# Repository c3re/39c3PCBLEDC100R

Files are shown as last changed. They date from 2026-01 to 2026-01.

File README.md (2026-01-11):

# 39c3PCBLEDC100R

The 39c3PCBLEDC100 is a Coaster for your drinks with option for LED and microcontroller upgrade. By stacking the coasters, you can also build nice blinky towers.

## Rev.0

### Electrical connections

Important: Do not power the board by USB and an external power supply at the same time!
The Din pin of the first LED is connected to pin D4 (GPIO2) of the Wemos D1 mini. ...well, not directly: there is a MOS-FET Transistor in between to shift the signal level from 3.3V to 5V. 
Two of the mounting holes are connected to GND, two of the holes are connected to 5V. You can use this feature to stack multiple 39c3PCBLEDc100R Boards with brass spacers.

The button is connected to D3 (GPIO0) and GND. In WLED (Time & Macros -> Button actions) you can configure actions for short, long and double click.

## License
    
39c3PCBLEDC100R © 2025 by c3RE is licensed under CC BY 4.0. To view a copy of this license,   
visit http://creativecommons.org/licenses/by/4.0/

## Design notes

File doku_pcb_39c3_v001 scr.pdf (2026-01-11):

# 39c3PCBLEDC100R

## D er 39c3P C B LE D C 10 0 R ist v ielleicht ein G eträn keu ntersetzer

m it d er O p tio n au f ein LE D ⁻ u n d M icro co ntro ller⁻U p d ate.

## D u kan nst d ie U ntersetzer stap eln u n d d ein en eigen en

b lin ken d en Tu rm u n d an d ere O b jekte b au en .

## M ayb e th e 39c3P C B LE D C 10 0 R is a coaster fo r yo u r d rin ks w ith o p tio n fo r LE D an d m icro co ntro ller u p grad e. By stackin g th e

coasters, yo u can also b u ild n ice b lin ky tow ers.

# Elektrische Verbindungen/Electrical connections

Wichtig: Schließe das Board nie gleichzeitig an USB und eine externe Spannungsversorgung an!

## Der Din Pin der ersten LED ist mit dem Pin D4 (GPIO4) des Wemos D1 mini verbunden. Zwei

Befestigungslöcher sind mit GND verbunden, die anderen beiden mit 5V. Du kannst damit mehrere PCBs mit Messingabstandhaltern verbinden.

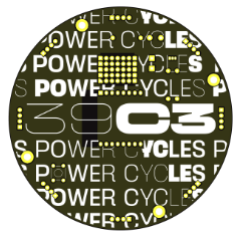
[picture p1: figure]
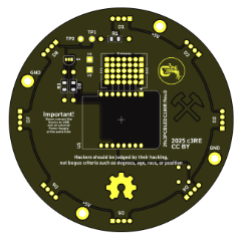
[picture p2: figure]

Important: Do not power the board by USB and an external power supply at the same time! The Din pin of the first LED is connected to pin D4 (GPIO2) of the Wemos D1 mini. Two of the mounting holes are connected to GND, two of the holes are connected to 5V. You can use this feature to stack multiple 39c3PCBLEDc100R Boards with brass spacers.

# Bevor es losgeht/before you start

Beginne mit den kleinsten Bauteilen in der Reihenfolge: Widerstände, Powerbutton, Mosfet, dann LEDs und zum Schluss den Microcontroller.
Start with components with the lowest height: Resistors, powerbutton, mosfet, then LEDs and finally the microcontroller.

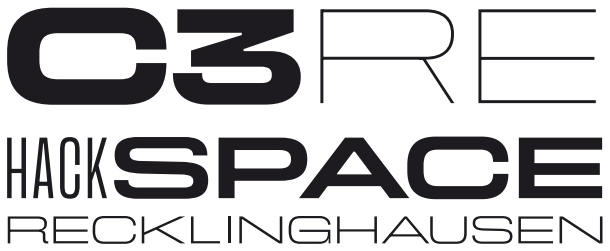
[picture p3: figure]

39c3PCBLEDC100R © 2025 by c3RE is licensed under CC BY 4.0.

github.com/c3re/39c3PCBLEDC100R | Licence | www.c3re.de

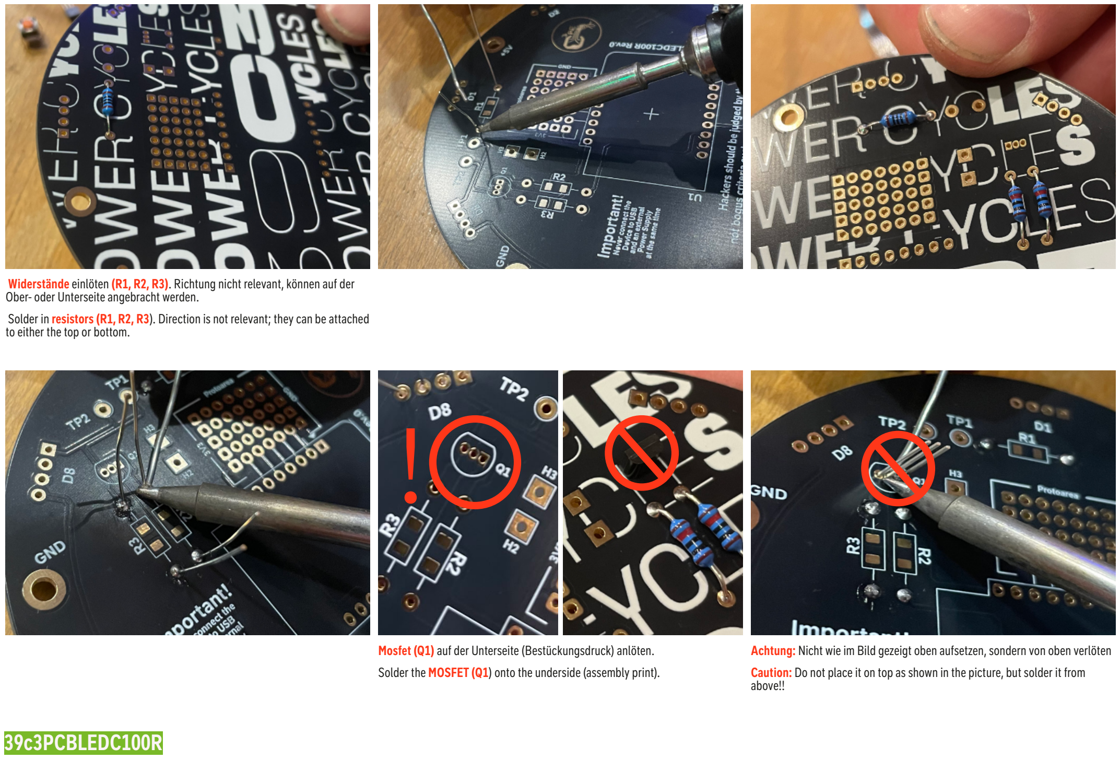
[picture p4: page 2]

## 39c3PCBLEDC100R

Widerstände einlöten (R1, R2, R3). Richtung nicht relevant, können auf der Ober- oder Unterseite angebracht werden.
Solder in resistors (R1, R2, R3). Direction is not relevant; they can be attached to either the top or bottom.

Mosfet (Q1) auf der Unterseite (Bestückungsdruck) anlöten.

Solder the MOSFET (Q1) onto the underside (assembly print).

Achtung: Nicht wie im Bild gezeigt oben aufsetzen, sondern von oben verlöten

Caution: Do not place it on top as shown in the picture, but solder it from above!!

!

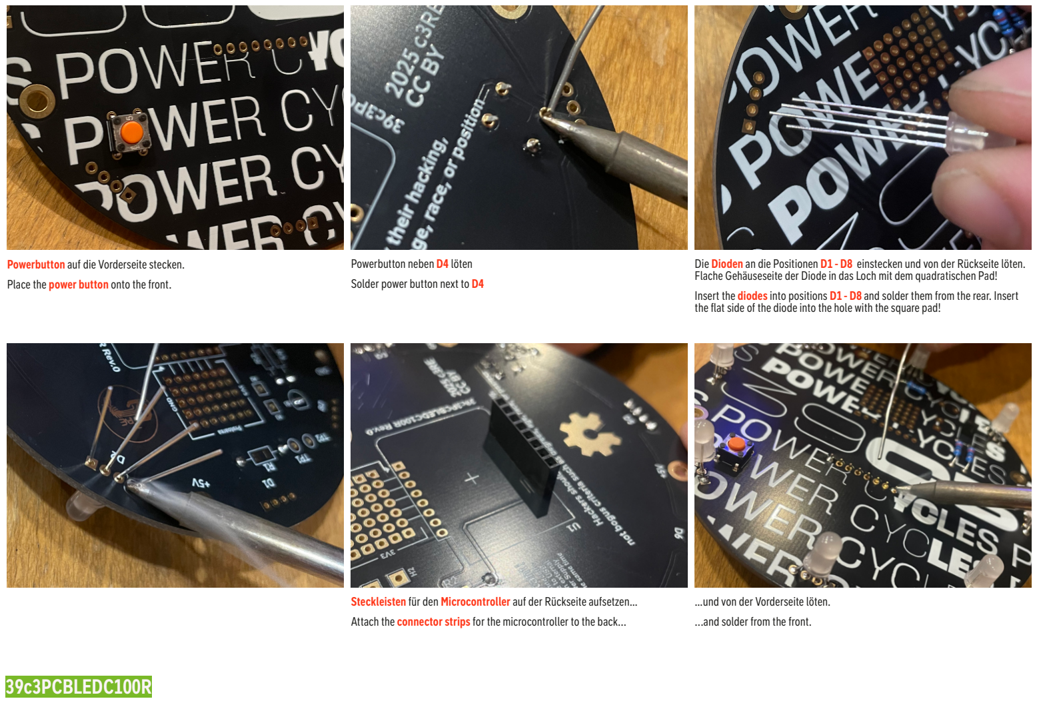
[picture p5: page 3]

## 39c3PCBLEDC100R

Powerbutton auf die Vorderseite stecken.

Place the power button onto the front.

Powerbutton neben D4 löten

Solder power button next to D4

Steckleisten für den Microcontroller auf der Rückseite aufsetzen…

Attach the connector strips for the microcontroller to the back...

Die Dioden an die Positionen D1 - D8 einstecken und von der Rückseite löten. Flache Gehäuseseite der Diode in das Loch mit dem quadratischen Pad!

Insert the diodes into positions D1 - D8 and solder them from the rear. Insert the flat side of the diode into the hole with the square pad!

…und von der Vorderseite löten.

...and solder from the front.

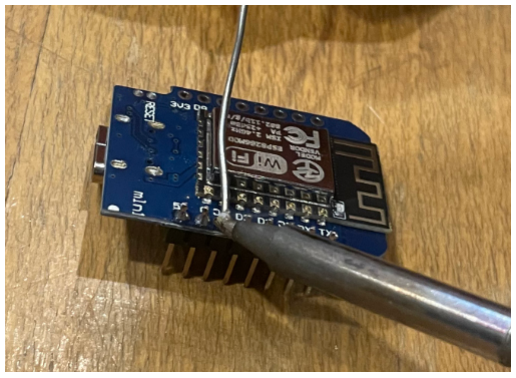
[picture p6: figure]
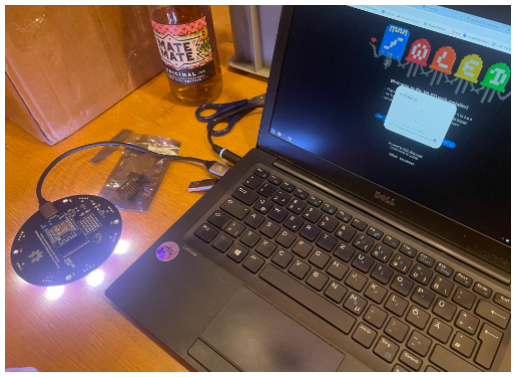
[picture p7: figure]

## 39c3PCBLEDC100R

Stiftleisten mit dem Microcontroller verbinden.

Connect pin strips to the microcontroller.

Enyoy!
https://install.wled.me/

https://www.zedfy.com/wled-anleitungen/wled-anleitung-hier-starten

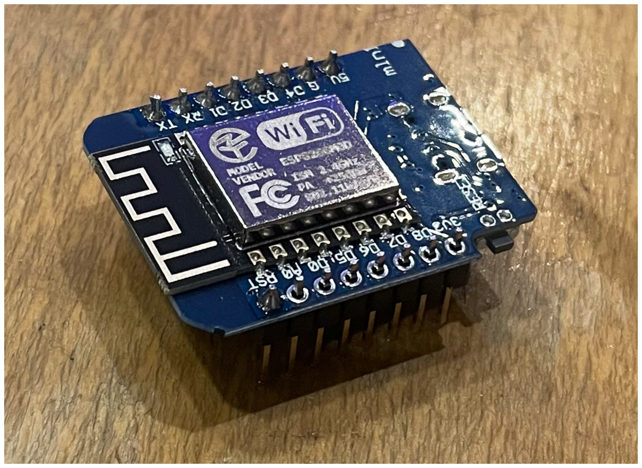
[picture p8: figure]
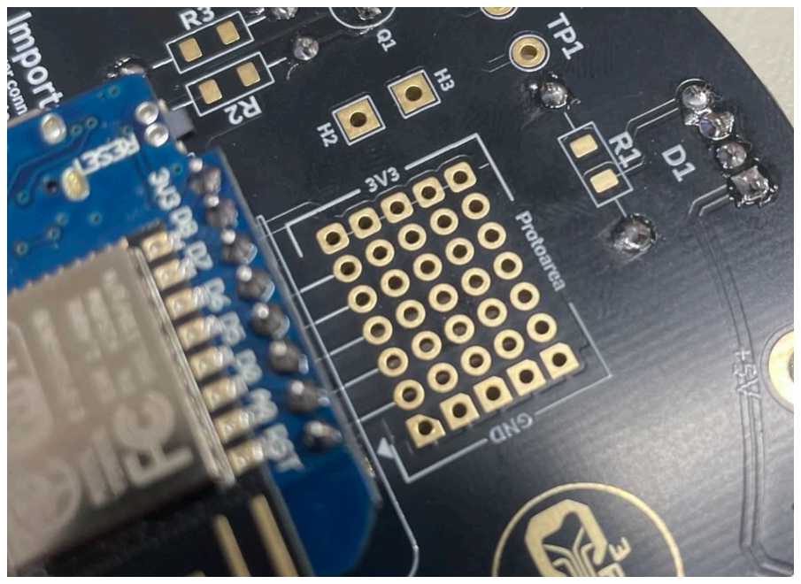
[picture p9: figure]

Die Protoarea kann mit zusätzlichen Sensoren etc. bestückt werden.

The Protoarea can be equipped with additional sensors, etc.

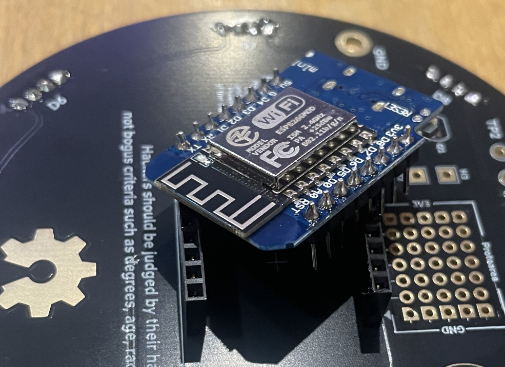
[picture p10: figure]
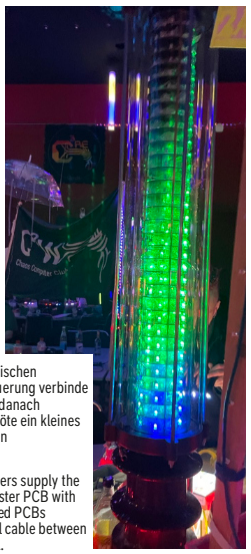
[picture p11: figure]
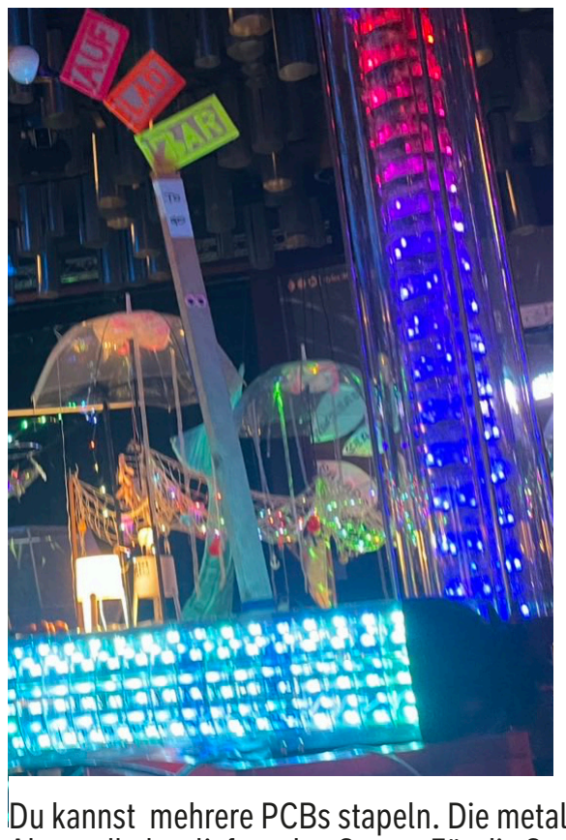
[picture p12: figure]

Du kannst mehrere PCBs stapeln. Die metallischen Abstandhalter liefern den Strom. Für die Steuerung verbinde den Master-PCB mit Microcontroller mit den danach verbundenen PCBs (ohne Controller). Dafür löte ein kleines Kabel zwischen Master TP2 und dem nächsten angeschlossenem PCB TP1.

You can stack multiple PCBs. The metal spacers supply the power. For control purposes, connect the master PCB with microcontroller to the subsequently connected PCBs (without controller). To do this, solder a small cable between master TP2 and the next connected PCB TP1.

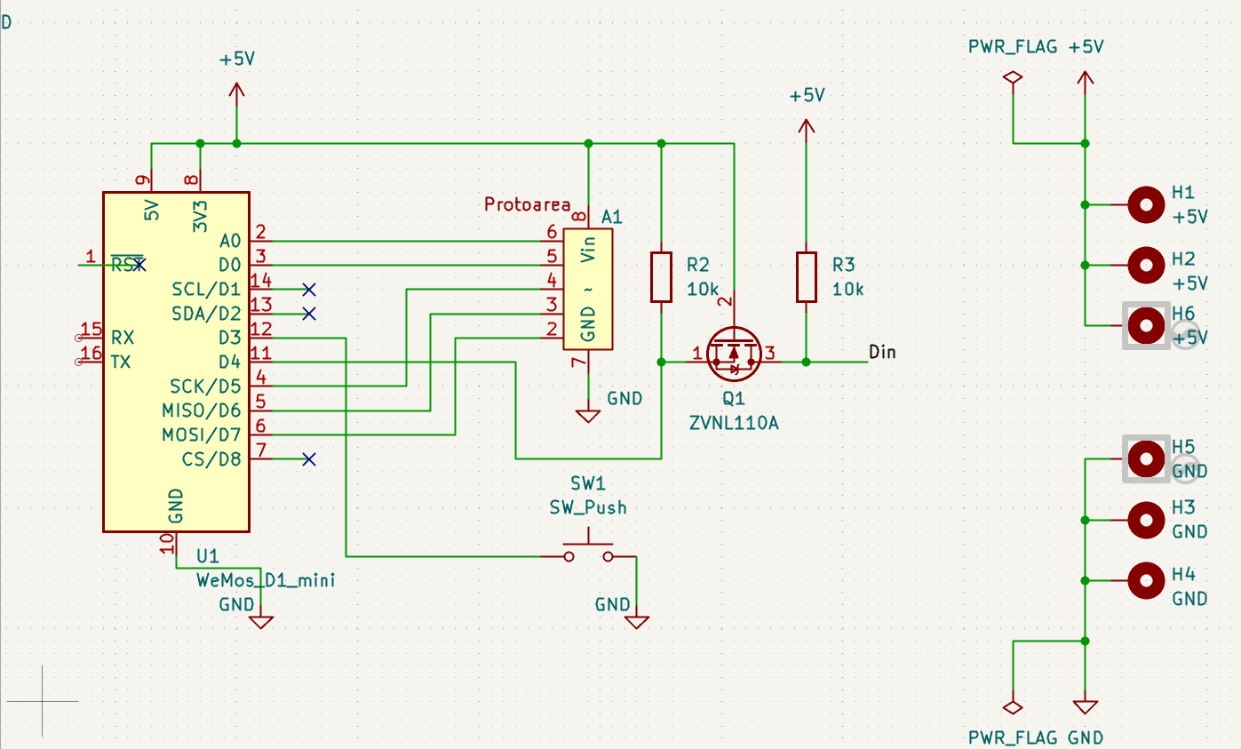
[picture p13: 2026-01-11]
Rev.0/Screenshot_20251224_004113.png

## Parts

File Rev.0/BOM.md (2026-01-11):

Pos.|Qty.|Designator|Description                      |Manufacturer|Part-No. (Manufacturer)|Vendor  |Part-No. (Vendor)
----|----|----------|---------------------------------|------------|-----------------------|--------|-----------------
1   |1   |R1        |Metal Film Resistor 100Ohm 250mW |VICO        |MF1/4W-100Ω±1%-OT52    |LCSC    |C2903231
2   |2   |R2-R3     |Metal Film Resistor 10kΩ 250mW   |YAGEO       |MFR-25FTE52-10K        |LCSC    |C172967
3   |1   |Q1        |MOSFET N-CH 100V 320MA TO92-3    |Diodes Inc. |ZVNL110A               |DigiKey |ZVNL110A-ND
4   |8   |D1-D8     |D=5mm RGB LED(Built-in IC)       |Worldsemi   |WS2812D-F5             |LCSC    |C190565
5   |4   |na        |Spacer                           |Shuntian    |M3X25+6                |LCSC    |C775782
6   |1   |SW1       |Switch SPST-NO                   |Omron       |B3F-1005               |LCSC    |C397293

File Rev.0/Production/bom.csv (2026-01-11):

Designator | Footprint | Quantity | Value | LCSC Part #
+5V_3, +5V_2 | MountingHole_3.2mm_M3_DIN965_Pad | 2 | +5V
A1 | Protoarea | 1 | ~
D1, D2, D3, D4, D5, D6, D7, D8 | WS2812_THT | 8 | WS2812D-F5 | C190565
DIN | TestPoint_THTPad_D2.5mm_Drill1.2mm | 1 | Din
DOUT | TestPoint_THTPad_D2.5mm_Drill1.2mm | 1 | Dout
GND_3, GND_2 | MountingHole_3.2mm_M3_DIN965_Pad | 2 | GND
Q1 | TO-92_Inline | 1 | ZVNL110A
R1 | 1206_combi_handsolder | 1 | 100
R2, R3 | 1206_combi_handsolder | 2 | 10k
SW1 | SW_TH_Tactile_Omron_B3F-102x | 1 | SW_SPST

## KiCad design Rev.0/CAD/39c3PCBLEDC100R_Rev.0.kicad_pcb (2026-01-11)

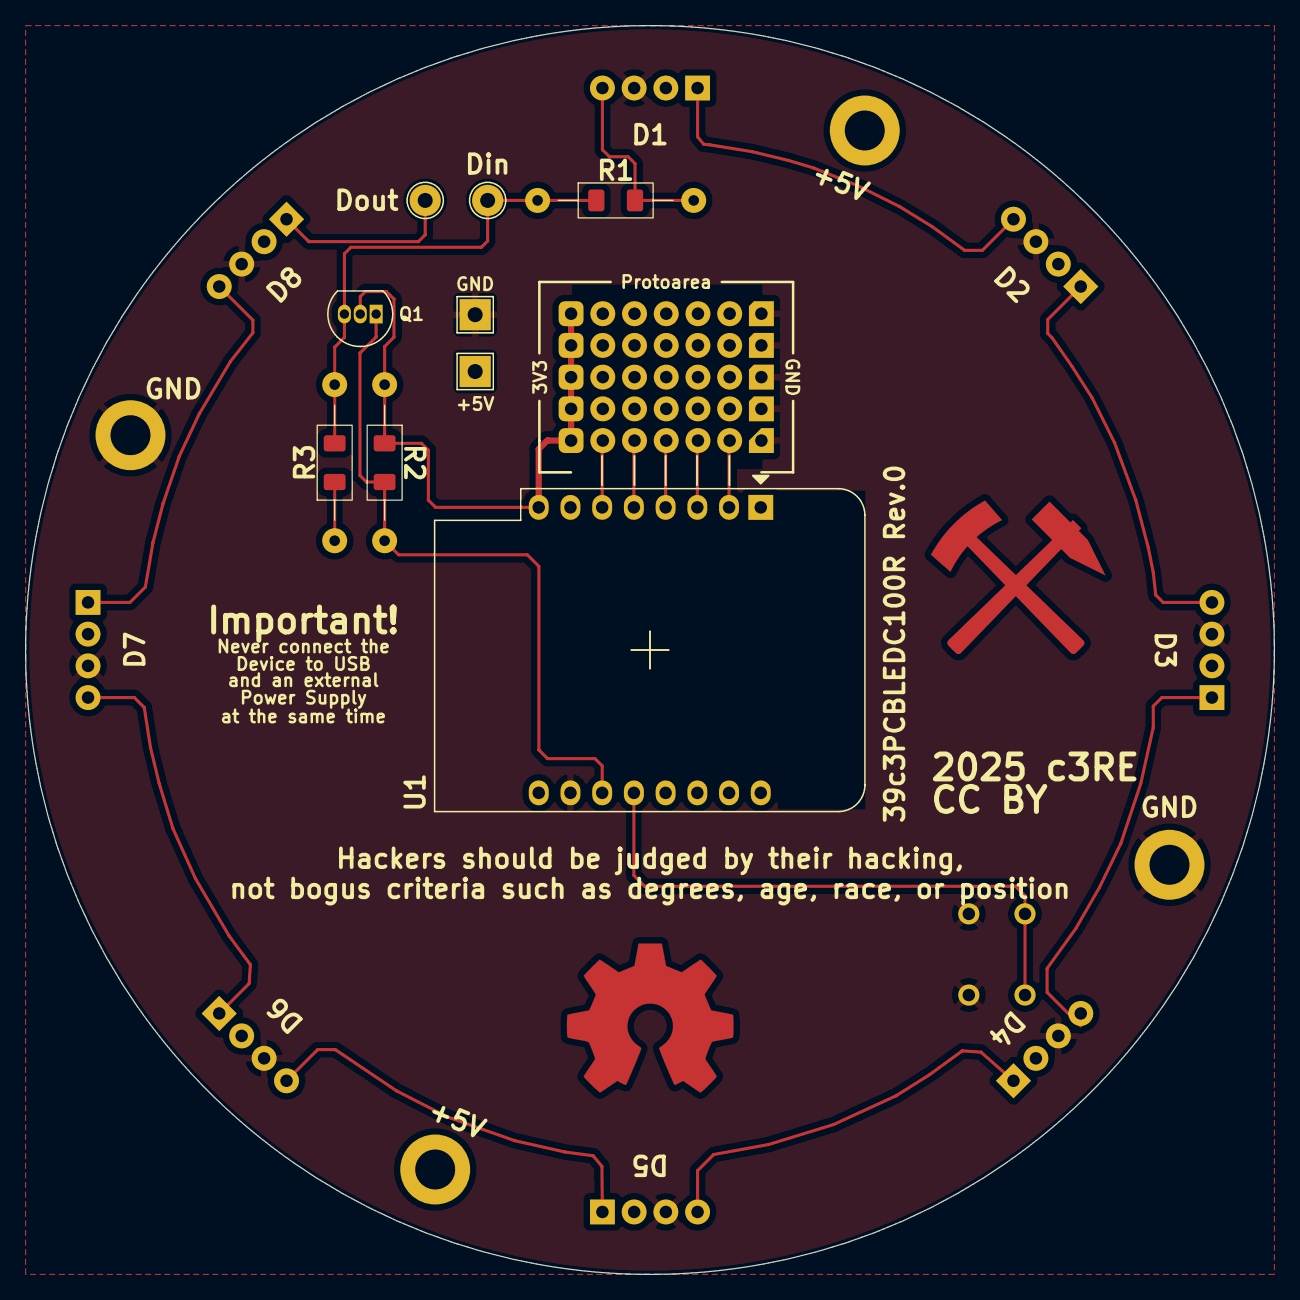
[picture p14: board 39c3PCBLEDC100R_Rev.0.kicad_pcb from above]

Board: 2 copper layers, 100.0 x 100.0 mm, 23 parts (1 on the bottom side), 20 nets.

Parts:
+5V, +5V#2: +5V; MountingHole_3.2mm_M3_DIN965_Pad
+5V#3: +5V; TestPoint_THTPad_2.5x2.5mm_Drill1.2mm
A1: Protoarea
D1, D2, D3, D4, D5, D6, D7, D8: WS2812D-F5; WS2812_THT
Din: Din; TestPoint_THTPad_D2.5mm_Drill1.2mm
Dout: Dout; TestPoint_THTPad_D2.5mm_Drill1.2mm
GND: GND; MountingHole_3.2mm_M3_DIN965_Pad
GND#2: GND; TestPoint_THTPad_2.5x2.5mm_Drill1.2mm
GND#3: GND; MountingHole_3.2mm_M3_DIN965_Pad
Q1: ZVNL110A; TO-92_Inline
R1: 100; 1206_combi_handsolder
R2, R3: 10k; 1206_combi_handsolder
SW1: SW_SPST; SW_TH_Tactile_Omron_B3F-102x
U1: WeMos_D1_mini; WEMOS_D1_mini_light

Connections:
+5V: +5V.1, +5V#2.1, +5V#3.1, D1.2 (VCC), D2.2 (VCC), D3.2 (VCC), D4.2 (VCC), D5.2 (VCC), D6.2 (VCC), D7.2 (VCC), D8.2 (VCC), R3.1, U1.9 (5V)
/Din: Din.1, Q1.3 (D), R1.1, R3.2
/Dout: D8.1 (DOUT), Dout.1
GND: A1.7 (GND), D1.3 (GND), D2.3 (GND), D3.3 (GND), D4.3 (GND), D5.3 (GND), D6.3 (GND), D7.3 (GND), D8.3 (GND), GND.1, GND#2.1, GND#3.1, SW1.2 (B), U1.10 (GND)
unnamed: A1.8 (Vin), Q1.2 (G), R2.1, U1.8 (3V3)
unnamed: D1.4 (DIN), R1.2
unnamed: D1.1 (DOUT), D2.4 (DIN)
unnamed: D2.1 (DOUT), D3.4 (DIN)
unnamed: D3.1 (DOUT), D4.4 (DIN)
unnamed: D4.1 (DOUT), D5.4 (DIN)
unnamed: D5.1 (DOUT), D6.4 (DIN)
unnamed: D6.1 (DOUT), D7.4 (DIN)
unnamed: D7.1 (DOUT), D8.4 (DIN)
unnamed: Q1.1 (S), R2.2, U1.11 (D4)
unnamed: SW1.1 (A), U1.12 (D3)
unnamed: A1.6, U1.2 (A0)
unnamed: A1.5, U1.3 (D0)
unnamed: A1.3, U1.5 (MISO/D6)
unnamed: A1.2, U1.6 (MOSI/D7)
unnamed: A1.4, U1.4 (SCK/D5)

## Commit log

2025-10-22 Added some files
    [39c3PCBLEDC100R_Rev.0.kicad_pcb, 39c3PCBLEDC100R_Rev.0.kicad_sch, BOM.csv]
2025-10-22 First commit of the updated Design files
    [39c3PCBLEDC100R_Rev.0.kicad_pcb, 39c3PCBLEDC100R_Rev.0.kicad_sch]
2025-12-22 Update README.md
    info about Button
2025-12-23 uploaded schematic PNG and build instructions PDF
2026-01-11 Added files for production & fixed some minor errors on the silkscreen
    [39c3PCBLEDC100R_Rev.0.kicad_pcb, 39c3PCBLEDC100R_Rev.0.kicad_sch, BOM.csv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]
